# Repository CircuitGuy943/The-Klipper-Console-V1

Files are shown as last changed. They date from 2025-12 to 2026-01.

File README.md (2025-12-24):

# The Klipper Console

The Klipper console is an 8 key (9 if you count the encoder) macropad with an OLED display and several LEDs designed to attach to the side of my Ender 3 (V2). As some of you may know, adding klipper and ender 3 renders the normal built in LCD useless, meaning I have to use my computer or other web capable device to access the GUI and actually control the printer. This is annoying because I can't do that while being right in front of the printer. This design adds some basic control and information by using the RP2040 as the MCU to collect all the data and show the print status through the chain of LEDs as a progress bar plus the LCD to show time remaining. It communicates with the Raspverry Pi board running klipper through the USB C connection and another script running on the Pi recieves the data and sends the HTTP requests to the Moonraker system to run the resulting GCODE commands.

## Features:
- Running Chase of LEDs shows progress visually
- 128x32 OLED Display
- EC11 Rotary encoder to easilly move the axis or change temperatures
- 9 Keys to send custom GCODE commands and macros

## CAD Model:
The PCB with the componenets simply drops in vertically into the Top part of the case. The bottom then slides in from underneath from the top and then screws in using the M3 bolts and heat inserts attached to the Top part. Hook 1 and Hook 2 are used to attach to the printer. The RPi support and Buttom Hook serve as an attachment method for the Raspverry Pi so that it is held close to the MCU and main design and doesn't hang around loosely. The Encoder cap can be printed also for a better aesthetic instead of just the bare EC11 knob. And finally I have also added some pieces meant to be acrylic covers for the LCD, Board display cutout and LEDs (I am aware Acrylic is not allowed but Orpheuspad's design has acrylic and I will add it myself after finishing the Blueprint project or I can just remove it if needed. But a frosted acrylic for the LEDs would look absolutely WILD):

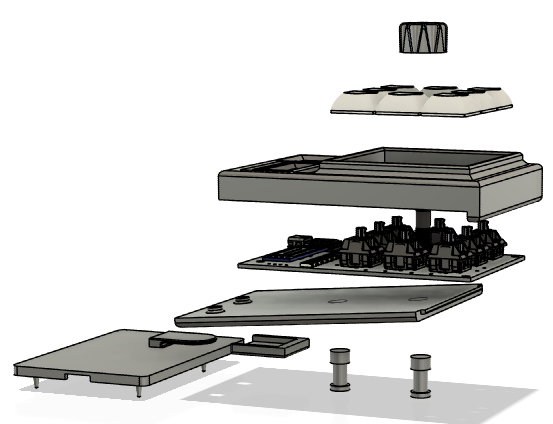
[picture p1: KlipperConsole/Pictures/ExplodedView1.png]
 

And here are the assembled views:

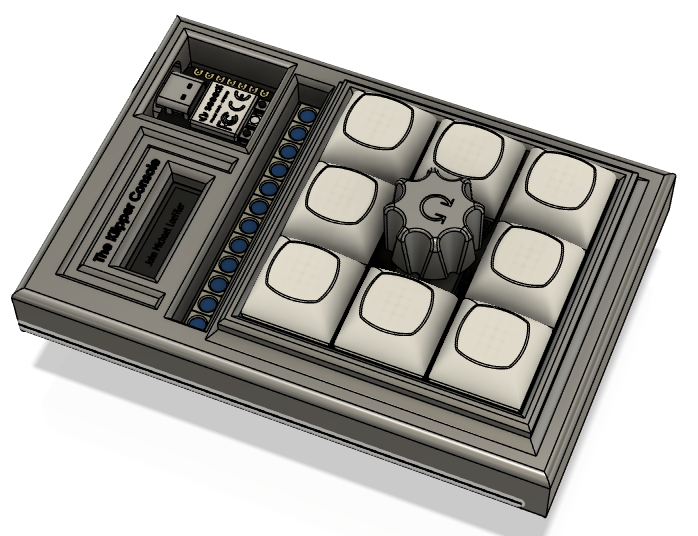
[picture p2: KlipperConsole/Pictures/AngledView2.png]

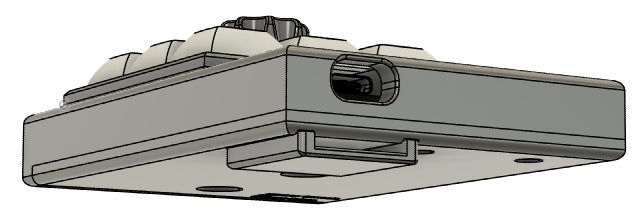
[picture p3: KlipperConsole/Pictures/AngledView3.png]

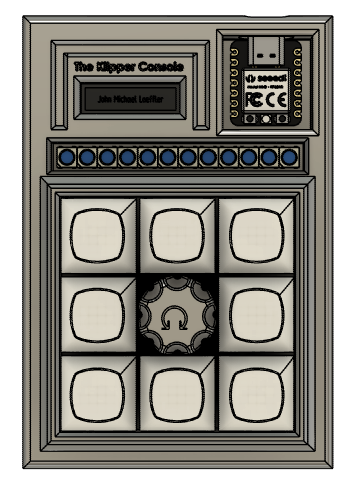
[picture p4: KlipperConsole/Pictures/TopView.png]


Designed in Fusion

## PCB
And this is my PCB. A bit difficult to include everything under 100mm but I managed to do it and got it to 65x100mm. Normal two layer PCB with copper ground areas:

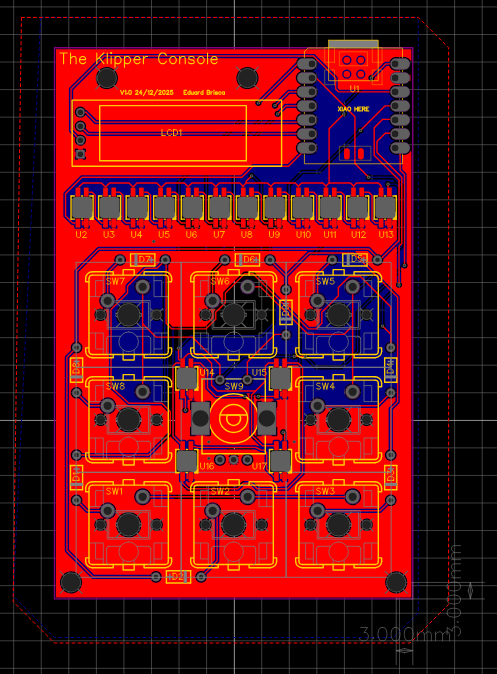
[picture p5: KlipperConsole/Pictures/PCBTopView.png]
PCB View
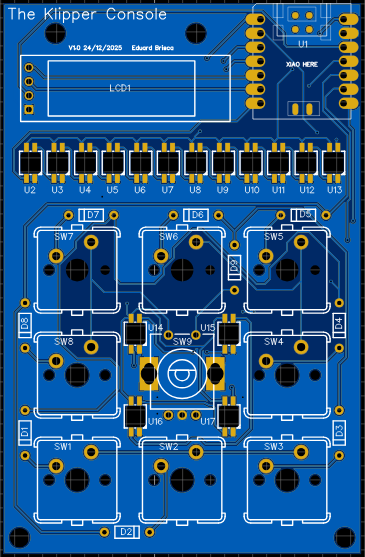
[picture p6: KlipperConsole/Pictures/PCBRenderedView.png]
PCB Rendered View
  

And the Schematic:

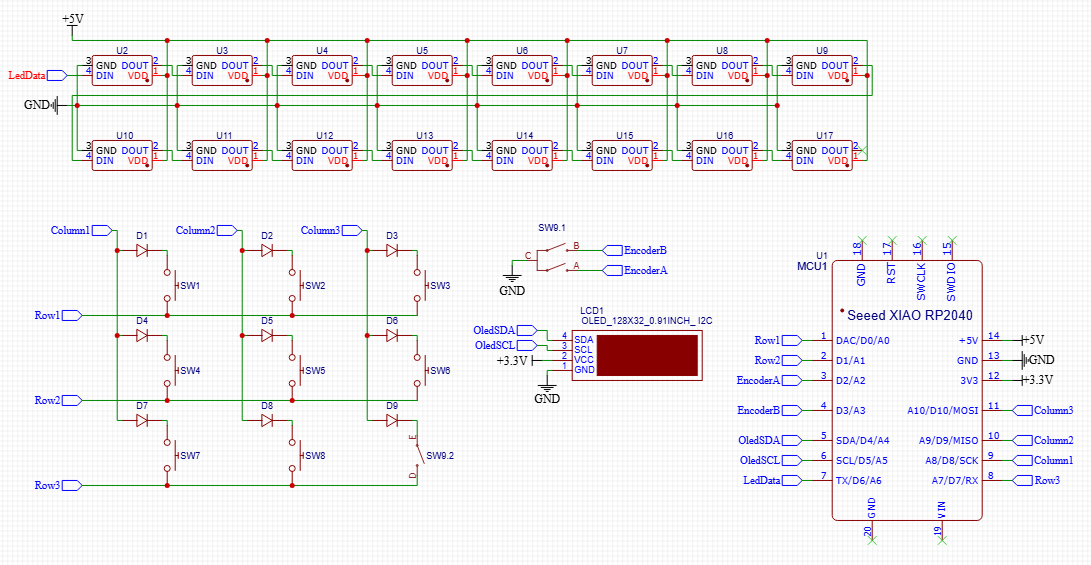
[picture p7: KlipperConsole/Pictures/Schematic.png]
Schematic


## Firmware Overview
The macropad iteself is programmed in Arduino IDE using C and the neccessary libraries for using all the componenets. It then also talks through serial through the USB to the RPi. The RPi also has a python script that read the serial data from the RP2040 and does transmits it to Moonraker. Currently I have the basic communication between the two MCU's setup and the functionality of all the components in code.

I'm excited to build it and add as many feautures, GCODE commands and Marcos as possible to my new printer Console.

## BOM:
I have included a .csv with the BOM list but here it is anyways.

- x9 1N4148
- x1 OLED_128X32_0.91INCH_ I2C
- x8 CHERRY MX
- x1 Seeed XIAO RP2040
- x16 SK6812MINI-E
- x1 EC11B-V-T
- x8 Blank DSA Keycaps
- x3 M3x16mm screws
- x3 M3x5mx4mm heatset inserts

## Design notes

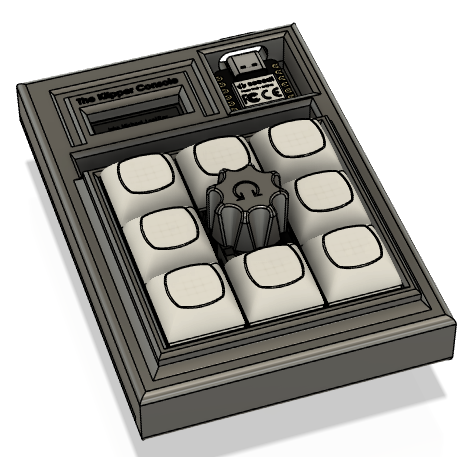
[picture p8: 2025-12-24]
Pictures/AngledView.png

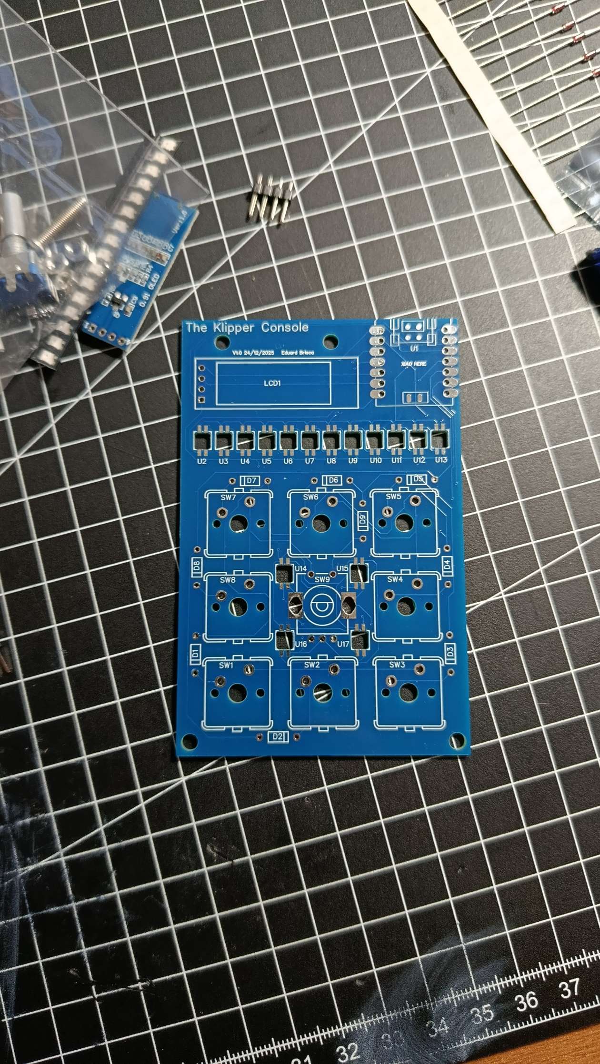
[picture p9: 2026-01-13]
Pictures/Snapchat-508537310.jpg

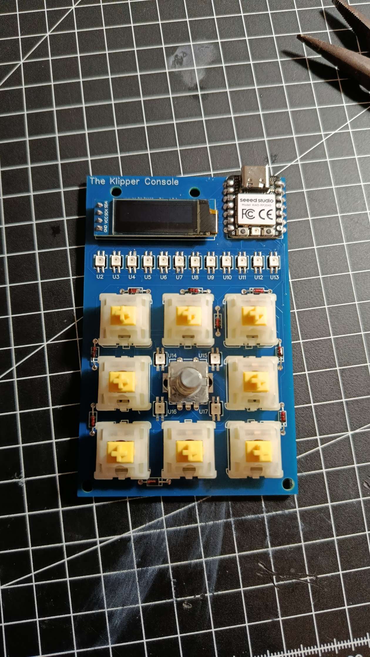
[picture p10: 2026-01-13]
Pictures/Snapchat-1397117244.jpg

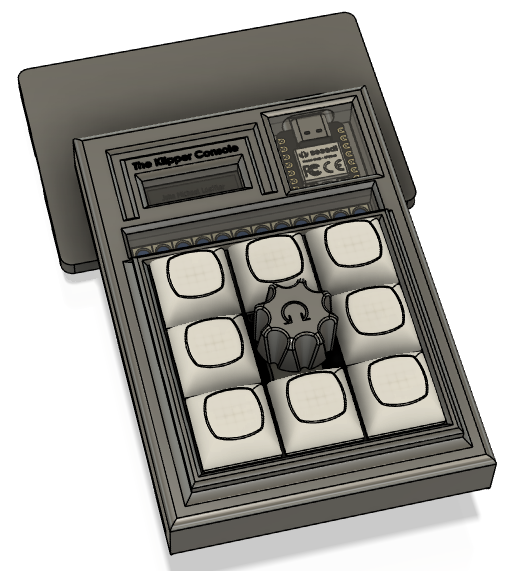
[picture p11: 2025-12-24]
Pictures/CompletedView.png

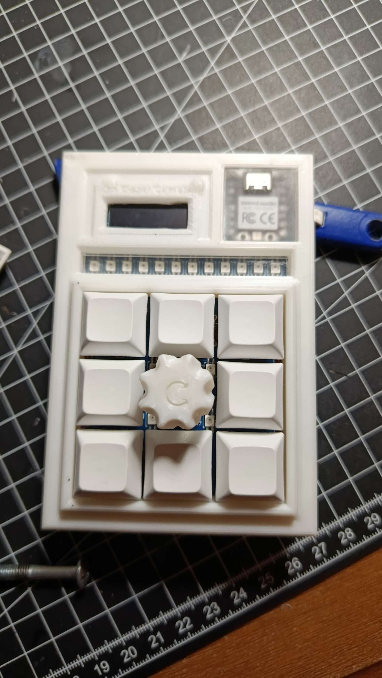
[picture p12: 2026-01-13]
Pictures/Snapchat-337838310.jpg

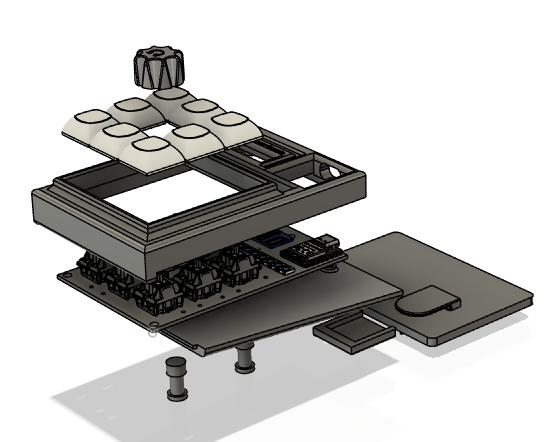
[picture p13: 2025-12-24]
Pictures/ExplodedView2.png

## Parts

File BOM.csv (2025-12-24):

Name | Quantity
1N4148 | 9
OLED_128X32_0.91INCH_ I2C | 1
CHERRY MX | 8
Seeed XIAO RP2040 | 1
SK6812MINI-E | 16
EC11B-V-T | 1
Blank DSA Keycaps | 8
M3x16mm screws | 3
M3x5mx4mm heatset inserts | 3

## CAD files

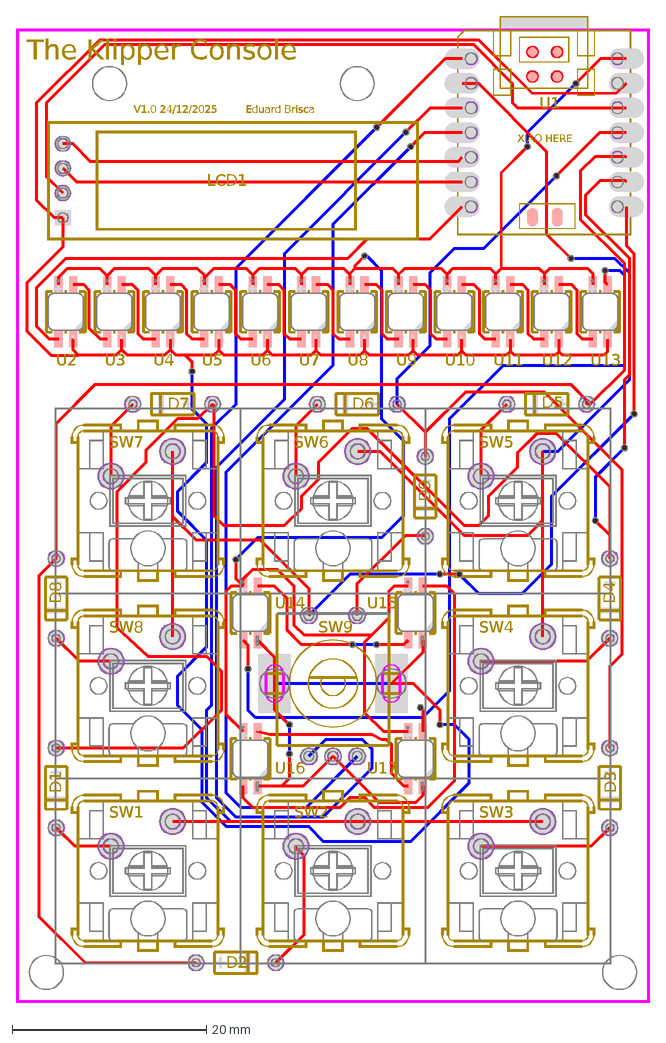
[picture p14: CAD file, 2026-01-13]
PCB/PCB.dxf
The Klipper Console
V1.0 24/12/2025
XIAO HERE
Eduard Brisca
D7
D8
D9
D1
D2
D3
D4
D5
D6
LCD1
SW1
SW2
SW3
SW4
SW5
SW6
SW7
SW8
U1
U2
U3
SW9
U4
U5
U6
U7
U8
U9
U10
U11
U12
U13
U14
U15
U16
U17

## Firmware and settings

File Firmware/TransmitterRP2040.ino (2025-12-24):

#include <Wire.h>
#include <Adafruit_GFX.h>
#include <Adafruit_SSD1306.h>
#include <Adafruit_NeoPixel.h>

#define ENCODER_CLK 2
#define ENCODER_DT  3
#define LED_PIN 6        // Data pin
#define NUM_LEDS 16      // Number of SK6812 MINI-E LEDs
#define SCREEN_WIDTH 128
#define SCREEN_HEIGHT 32
#define OLED_RESET    -1  // Not used
#define SCREEN_ADDRESS 0x3C  // Common I2C address, needs testing and changing to correct one

Adafruit_NeoPixel strip(NUM_LEDS, LED_PIN, NEO_GRB + NEO_KHZ800);
Adafruit_SSD1306 display(SCREEN_WIDTH, SCREEN_HEIGHT, &Wire, OLED_RESET);

volatile int encoderPos = 0;  // Counter
int lastCLK = LOW;

// Matrix size
const uint8_t ROW_COUNT = 3;
const uint8_t COL_COUNT = 3;

// Pin assignments
const uint8_t ROW_PINS[ROW_COUNT] = {0, 1, 7};
const uint8_t COL_PINS[COL_COUNT] = {8, 9, 10};

// Matrix data to be transferred
//                R1------- R2------ R3------
uint8_t data[] = {0, 0, 0, 0, 0, 0, 0, 0, 0};
//                C1 C2 C3 C1 C2 C3 C1 C2 C3

// Setup
void setup() {
  Serial.begin(115200);

  // Rows: inputs with internal pull-downs
  for (uint8_t row = 0; row < ROW_COUNT; row++) {
    pinMode(ROW_PINS[row], INPUT_PULLDOWN);
  }

  // Columns: outputs, idle LOW
  for (uint8_t col = 0; col < COL_COUNT; col++) {
    pinMode(COL_PINS[col], OUTPUT);
    digitalWrite(COL_PINS[col], LOW);
  }

  Wire.begin();  // Initialize I2C

  if(!display.begin(SSD1306_SWITCHCAPVCC, SCREEN_ADDRESS)) {
    Serial.println(F("SSD1306 allocation failed"));
    for(;;);
  }

  display.clearDisplay();
  display.display();

  display.setTextSize(1);
  display.setTextColor(SSD1306_WHITE);
  display.setCursor(0,0);
  display.println("Hello RP2040");
  display.display();

  strip.begin();
  strip.show(); // Initialize all pixels to 'off'

  for(int i=0; i<NUM_LEDS; i++){
    strip.setPixelColor(i, strip.Color(255, 0, 0)); // Red
  }
  strip.show();

  pinMode(ENCODER_CLK, INPUT_PULLUP);
  pinMode(ENCODER_DT, INPUT_PULLUP);

  lastCLK = digitalRead(ENCODER_CLK);
}

// Main loop
void loop() {

  //Read matrix
  scanMatrix();

  // Read encoder
  int clkState = digitalRead(ENCODER_CLK);
  if(clkState != lastCLK) { // rotation detected
    if(digitalRead(ENCODER_DT) != clkState) {
      encoderPos++;  // clockwise
    } else {
      encoderPos--;  // counter-clockwise
    }
    Serial.print("Position: "); Serial.println(encoderPos);
  }
  lastCLK = clkState;

  // Send Array over serial
  void sendArray() {
    Serial.write(0xAA);                 // start byte
    Serial.write(sizeof(data));         // length
    Serial.write(data, sizeof(data));   // payload
    Serial.write(0x55);                 // end byte
  }

  delay(5); // debounce window
}

// Matrix scan
void scanMatrix() {

  for (uint8_t col = 0; col < COL_COUNT; col++) {

    // Drive one column HIGH
    digitalWrite(COL_PINS[col], HIGH);
    delayMicroseconds(3); // signal settle time

    // Read all rows
    for (uint8_t row = 0; row < ROW_COUNT; row++) {

      bool pressed = (digitalRead(ROW_PINS[row]) == HIGH);

      if (pressed) {
        data[row*3 + col ] = pressed
      }
    }

    // Return column to idle LOW
    digitalWrite(COL_PINS[col], LOW);
  }

  return data
}

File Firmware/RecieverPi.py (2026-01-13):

import serial

START_BYTE = 0xAA
END_BYTE   = 0x55
MAX_PAYLOAD = 32

ser = serial.Serial(
    port='/dev/serial0',
    baudrate=115200,
    timeout=0.1
)

state = "WAIT_START"
length = 0
payload = bytearray()

while True:
    if ser.in_waiting == 0:
        continue

    byte_in = ser.read(1)[0]

    if state == "WAIT_START":
        if byte_in == START_BYTE:
            state = "READ_LENGTH"

    elif state == "READ_LENGTH":
        length = byte_in
        if length > MAX_PAYLOAD:
            state = "WAIT_START"
        else:
            payload.clear()
            state = "READ_PAYLOAD"

    elif state == "READ_PAYLOAD":
        payload.append(byte_in)
        if len(payload) >= length:
            state = "WAIT_END"

    elif state == "WAIT_END":
        if byte_in == END_BYTE:
            print("Packet received:", list(payload))
        state = "WAIT_START"
